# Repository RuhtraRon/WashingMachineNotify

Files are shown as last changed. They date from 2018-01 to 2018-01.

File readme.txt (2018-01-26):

Install the toolchain following:

https://github.com/espressif/arduino-esp32

(which really is just download the repo to specific folder and run get.py)

If the drivers don't autmatically load when connecting with USB, follow:

https://wiki.wemos.cc/downloads

BILL OF MATERIALS:

Descriptoin	Part Number	Cost	Shipping	Quantity	Total
Microprocessor	Lolin32 lite	$4.90	$1.81		1		$4.90
Accelerometer	LIS3DH		$4.95	$10		1		$4.95
Battery		2000mAh		$12.50	^		1		$12.50
Motherboard			$4.95	free		1		$4.95
Case				$19.76	free		1		$19.76
Magnets				$0.26	free		2		$0.52
Headers	Female			$0.04	^		36		$1.59
Headers	Male			$0.01	^		36		$0.50

Needed Libraries Included

Gerber files for motherboard in zip file included

STL for enclosure included (needes updated)

To Use End Product:
Power device on (connect battery)
Use smartphone or computer to connect to SSID 'WashingMachine'
If captive portal doesn't launch, point browser to 192.168.4.1
Follow prompts, select your SSID, enter Wifi password, Ifttt Event Name, and Ifttt Maker Key
    Ifttt maker key can be found at https://ifttt.com/maker_webhooks, click Documentation
    Make sure to add the webhooks service first, and create the applet you want fired
To restore to factory settings, press Reset button or power off device

Values to change in WashingMachineNotify.ino:
#define TIME_TO_SLEEP  300      /* Snooze time between re-notifies */
#define AWAKE_TIME 10000 //milliseconds to wait for another vibration before sleep
#define NOTIFY_THRESHOLD 270000 //milliseconds of vibration before sending notification
#define TIMEOUT 120 //seconds for capture portal to be active
#define NOTIFY_DELAY 120 //seconds to wait before sending first notify

Todo: 
Update to Wemos Lolin32 (not lite)

Sources:
Accelerometer - https://github.com/alexspurling/washingmachine
WifiManger - https://github.com/zhouhan0126/WIFIMANAGER-ESP32

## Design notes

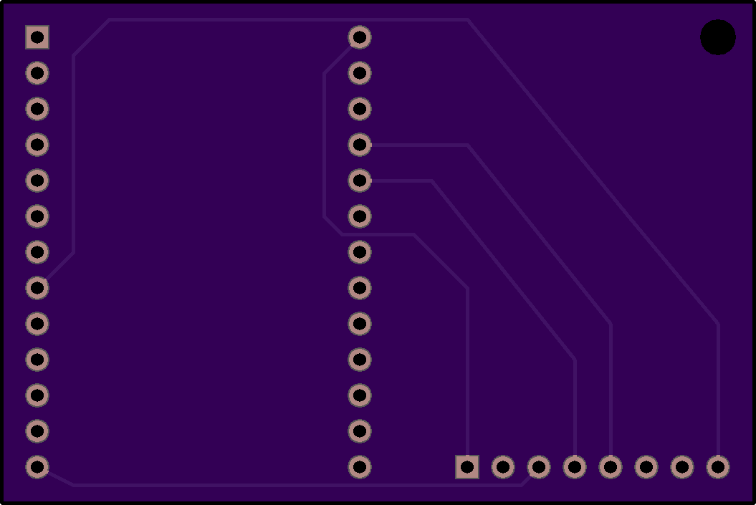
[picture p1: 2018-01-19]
wmnotify.png

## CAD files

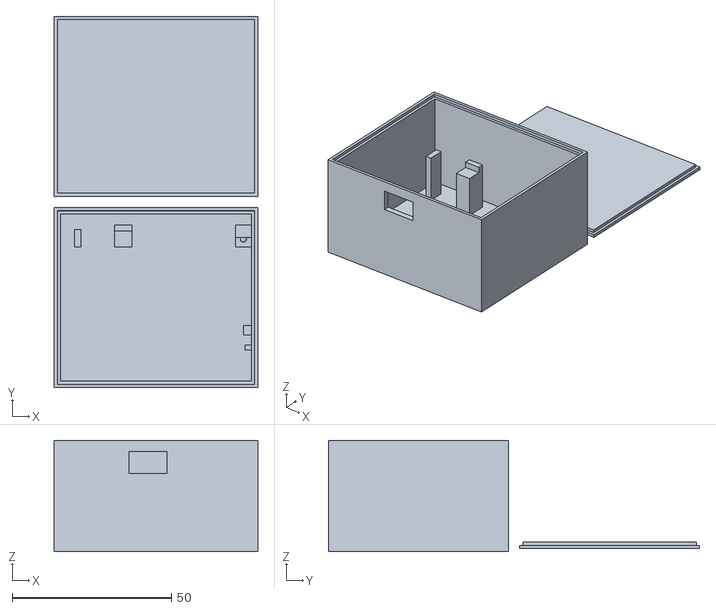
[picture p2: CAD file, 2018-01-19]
WashingMachineBox.stl
64.0 x 116.5 x 35.0

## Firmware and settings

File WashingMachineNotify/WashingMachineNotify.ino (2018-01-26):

#include <WiFi.h>
#include <rom/rtc.h>
#include <DNSServer.h>
#include <WebServer.h>
#include <WiFiManager.h>
#include <WiFiClientSecure.h>
#include <IFTTTMaker.h>
#include "time.h"

#define SDA_PIN 23
#define SCL_PIN 18

RTC_DATA_ATTR char event_name[64] = "IFTTT_EVENT_NAME";
RTC_DATA_ATTR char ifttt_key[32] = "IFTTT_MAKER_KEY";

#define ACCEL 0x18 //I2C device address
#define CTRL_REG1 0x20 //Data rate selection and X, Y, Z axis enable register
#define CTRL_REG2 0x21 //High pass filter selection
#define CTRL_REG3 0x22 //Control interrupts
#define CTRL_REG4 0x23 //BDU
#define CTRL_REG5 0x24 //FIFO enable / latch interrupts

#define INT1_CFG 0x30 //Interrupt 1 config
#define INT1_SRC 0x31 //Interrupt status - read in order to reset the latch
#define INT1_THS 0x32 //Define threshold in mg to trigger interrupt
#define INT1_DURATION 0x33 //Define duration for the interrupt to be recognised (not sure about this one)

//Read this value to set the reference values against which accel values are compared when calculating a threshold interrupt
//Also called the REFERENCE register in the datasheet
#define HP_FILTER_RESET 0x26 

#define REG_X 0x28
#define REG_Y 0x2A
#define REG_Z 0x2C

#define uS_TO_S_FACTOR 1000000  /* Conversion factor for micro seconds to seconds */
#define TIME_TO_SLEEP  300      /* Snooze time between re-notifies */
#define AWAKE_TIME 10000 //milliseconds to wait for another vibration before sleep
#define NOTIFY_THRESHOLD 270000 //milliseconds of vibration before sending notification
#define TIMEOUT 120 //seconds for capture portal to be active
#define NOTIFY_DELAY 120 //seconds to wait before sending first notify

const char* ntpServer = "pool.ntp.org";
const long  gmtOffset_sec = -18000;
const int   daylightOffset_sec = 3600;

bool button_press = false;

const int ledPin = 22;
int ledState = HIGH;
const int intPin = 25;

WiFiClientSecure secureclient;
IFTTTMaker ifttt(ifttt_key, secureclient);

WiFiManager wifiManager;

RTC_DATA_ATTR int bootCount = 0;
RTC_DATA_ATTR int prevState = 0;
RTC_DATA_ATTR bool renotify = false;
RTC_DATA_ATTR bool first_notify = false;
unsigned long bootTime = 0;
unsigned long machineOffTime = 0;
unsigned long blinkTime = 0;
unsigned long startWM = 0;

RTC_DATA_ATTR struct tm first_notify_time;

void blinkLed(){
  ledState = !ledState;
  digitalWrite(ledPin, ledState);
}

void print_wakeup_reason(){
  esp_sleep_wakeup_cause_t wakeup_reason;

  wakeup_reason = esp_sleep_get_wakeup_cause();
  Serial.print("wakeup_reason: ");
  Serial.println(wakeup_reason);
  switch(wakeup_reason)
  {
    case 1  : Serial.println("Wakeup caused by external signal using RTC_IO"); break; //if(!first_notify){renotify=false;}
    case 2  : Serial.println("Wakeup caused by external signal using RTC_CNTL"); break;
    case 3  : Serial.println("Wakeup caused by timer"); break;
    case 4  : Serial.println("Wakeup caused by touchpad"); break;
    case 5  : Serial.println("Wakeup caused by ULP program"); break;
    default : Serial.println("Wakeup was not caused by deep sleep"); renotify=false; first_notify = false; break;
  }
}

void verbose_print_reset_reason(RESET_REASON reason)
{
  switch ( reason)
  {
    case 1  : Serial.println ("Vbat power on reset"); button_press=true; break;
    case 3  : Serial.println ("Software reset digital core");break;
    case 4  : Serial.println ("Legacy watch dog reset digital core");break;
    case 5  : Serial.println ("Deep Sleep reset digital core");break;
    case 6  : Serial.println ("Reset by SLC module, reset digital core");break;
    case 7  : Serial.println ("Timer Group0 Watch dog reset digital core");break;
    case 8  : Serial.println ("Timer Group1 Watch dog reset digital core");break;
    case 9  : Serial.println ("RTC Watch dog Reset digital core");break;
    case 10 : Serial.println ("Instrusion tested to reset CPU");break;
    case 11 : Serial.println ("Time Group reset CPU");break;
    case 12 : Serial.println ("Software reset CPU");break;
    case 13 : Serial.println ("RTC Watch dog Reset CPU");break;
    case 14 : Serial.println ("for APP CPU, reseted by PRO CPU");break;
    case 15 : Serial.println ("Reset when the vdd voltage is not stable");break;
    case 16 : Serial.println ("RTC Watch dog reset digital core and rtc module");button_press=true;break;
    default : Serial.println ("NO_MEAN");
  }
}

void wifiConfig(){
  #define STA_SSID "YOUR_SSID"
  #define STA_PASS "YOUR_PASSWORD"
  WiFi.begin(STA_SSID, STA_PASS);
  wifiWait();
}

void wifiWait(){
    Serial.println("Waiting for WiFi");
    int wifi_wait_count = 30;
    int count = 0;
    while ((WiFi.status() != WL_CONNECTED)&&(count < wifi_wait_count)) {
        delay(500);
        Serial.print(".");
        count++;
    }
    if (count >= wifi_wait_count){
      esp_sleep_enable_timer_wakeup(1 * uS_TO_S_FACTOR);
      esp_deep_sleep_start();
    }
    Serial.println("");
    Serial.println("WiFi connected");
    Serial.println("IP address: ");
    Serial.println(WiFi.localIP());
}

void printAccel(int vibrations) {
  float x = getAccel(readReg(REG_X));
  float y = getAccel(readReg(REG_Y));
  float z = getAccel(readReg(REG_Z));

  Serial.print("Read: ");
  printFloat(x, 3);
  Serial.print(", ");
  printFloat(y, 3);
  Serial.print(", ");
  printFloat(z, 3);
  Serial.print(", ");
  Serial.println(vibrations);
  
  writeReg(INT1_CFG, 0x2a);
}

void iftttsend(){
  //triggerEvent takes an Event Name and then you can optional pass in up to 3 extra Strings
  if(ifttt.triggerEvent(event_name)){
    Serial.println("IFTTT Successfully sent");
  } else
  {
    Serial.println("IFTTT Failed!");
  }
}

struct tm timeinfo;
void printLocalTime()
{
  if(!getLocalTime(&timeinfo)){
    Serial.println("Failed to obtain time");
    return;
  }
  Serial.println(&timeinfo, "%A, %B %d %Y %H:%M:%S");
}

void setupAccel(){
  writeReg(CTRL_REG1, 0x47); //Set data rate to 50hz. Enable X, Y and Z axes
  //1 - BDU: Block data update. This ensures that both the high and the low bytes for each 16bit represent the same sample
  //0 - BLE: Big/little endian. Set to little endian
  //00 - FS1-FS0: Full scale selection. 00 represents +-2g
  //1 - HR: High resolution mode enabled.
  //00 - ST1-ST0: Self test. Disabled
  //0 - SIM: SPI serial interface mode. Default is 0.
  writeReg(CTRL_REG4, 0x88);
  writeReg(CTRL_REG2, 0x09);//2 Write 09h into CTRL_REG2 // High-pass filter enabled on data and interrupt1
  writeReg(CTRL_REG3, 0x40);//3 Write 40h into CTRL_REG3 // Interrupt driven to INT1 pad
  //4 Write 00h into CTRL_REG4 // FS = 2 g
  writeReg(CTRL_REG5, 0x08);//5 Write 08h into CTRL_REG5 // Interrupt latched
  writeReg(INT1_THS, 0x04);// Threshold as a multiple of 16mg. 4 * 16 = 64mg
  writeReg(INT1_DURATION, 0x00);// Duration = 0 not quite sure what this does yet
  // Read the reference register to set the reference acceleration values against which
  // we compare current values for interrupt generation
  readReg(HP_FILTER_RESET);//8 Read HP_FILTER_RESET
  writeReg(INT1_CFG, 0x2a);//9 Write 2Ah into INT1_CFG // Configure interrupt when any of the X, Y or Z axes exceeds (rather than stay below) the threshold
  readReg(INT1_SRC);
}

void wifiManagerConfig(){
  // The extra parameters to be configured (can be either global or just in the setup)
  // After connecting, parameter.getValue() will get you the configured value
  // id/name placeholder/prompt default length

  WiFiManagerParameter custom_event_name("name", "event name", event_name, 64);
  WiFiManagerParameter custom_ifttt_key("key", "ifttt key", ifttt_key, 32);

  wifiManager.addParameter(&custom_event_name);
  wifiManager.addParameter(&custom_ifttt_key);

  wifiManager.setBreakAfterConfig(true);
  wifiManager.setConfigPortalTimeout(TIMEOUT);

  startWM = millis();
  
  if (!button_press){
    wifiManager.autoConnect("WashingMachine");
  } else {
    wifiManager.startConfigPortal("WashingMachine");
  }
  
  if ((WiFi.status() != WL_CONNECTED)&&(millis() > startWM + (TIMEOUT*1000))){ //setConfigPortalTimeout must have triggered
    Serial.println("Going to sleep, portal timeout");
    esp_deep_sleep_start();
  }
  strcpy(event_name, custom_event_name.getValue());
  strcpy(ifttt_key, custom_ifttt_key.getValue());

  Serial.print("event_name: ");
  Serial.println(event_name);
  Serial.print("ifttt_key: ");
  Serial.println(ifttt_key);

  wifiWait();
}

void setup() {
  Serial.begin(115200);
  ++bootCount;
  Serial.println("Boot number: " + String(bootCount));
  pinMode(ledPin, OUTPUT);
  digitalWrite(ledPin, ledState); //off
  print_wakeup_reason();
  verbose_print_reset_reason(rtc_get_reset_reason(0));
  initI2C();
  setupAccel();
  pinMode(intPin, INPUT);
  attachInterrupt(intPin, wakeUp, RISING);
  Serial.println("Accelerometer enabled");
  
  esp_sleep_enable_ext0_wakeup(GPIO_NUM_25, HIGH);

  blinkLed(); //on

  wifiManagerConfig();
//  wifiConfig();

  blinkLed(); //off
  bootTime = millis();
  Serial.print("Re-notify: ");
  Serial.println(renotify);
  configTime(gmtOffset_sec, daylightOffset_sec, ntpServer);
  printLocalTime();
  Serial.println(&first_notify_time, "%A, %B %d %Y %H:%M:%S");
}

float getAccel(int16_t accel) {
  return float(accel) / 16000;
}

volatile bool machineOn = false;
volatile unsigned int vibrations = 0;
unsigned int prev_vibrations = 0;

int activeLoopInterval = 200; //Loop 5 times a second

bool started = false;
float readdata = 0.0;

void loop() {  
  if (!started) { //first power on
      started = true;
      //Reset the interrupt when we are actually ready to receive it
      readReg(INT1_SRC);
    }
  if (machineOn) {
    readReg(INT1_SRC);
    delay(activeLoopInterval);
    blinkLed();
    printAccel(vibrations);

    if (vibrations > prev_vibrations){
      prev_vibrations = vibrations;
    } else{
      machineOn = false;
      machineOffTime = millis();
    }
    if (renotify && vibrations > 10){
      renotify = false;
      int i = 100;
      while (i >0){
        blinkLed();
        delay(50);
        i--;
      }
    }
  } else if (millis() - machineOffTime > AWAKE_TIME) {
    if ((millis() - bootTime > (NOTIFY_THRESHOLD)) || renotify) {
      if (!renotify){
        first_notify = true;
        Serial.println("Turning first_notify on");
        getLocalTime(&first_notify_time);
        Serial.print("Setting first_notify_time: ");
        Serial.println(&first_notify_time, "%A, %B %d %Y %H:%M:%S");
        renotify = true;
        Serial.println("Re-notify On");
      }
      printLocalTime();
      double notifydifftime = difftime(mktime(&timeinfo),mktime(&first_notify_time));
      Serial.print("Time Diff: ");
      Serial.println(notifydifftime);
      int sleep_time = 0;
      if (first_notify){
        sleep_time = (NOTIFY_DELAY-notifydifftime);
      } else {
        sleep_time = (TIME_TO_SLEEP-notifydifftime);
      }
      if (sleep_time < 0) {
        iftttsend();
        first_notify = false;
        Serial.println("Turning first_notify off");
        getLocalTime(&first_notify_time);
        Serial.print("Setting first_notify_time: ");
        Serial.println(&first_notify_time, "%A, %B %d %Y %H:%M:%S");
        sleep_time = TIME_TO_SLEEP;
      }
      esp_sleep_enable_timer_wakeup(sleep_time * uS_TO_S_FACTOR);
      Serial.print("Sleeping for: ");
      Serial.println(sleep_time);
    }
    writeReg(CTRL_REG1, 0x2f); //Set data rate to 1z. Enable X, Y and Z axes in low power mode
    writeReg(CTRL_REG4, 0x0); //Turn off BDU, turn off high precision mode
    readReg(HP_FILTER_RESET); //Reset the reference state (seems to be necessary when changing the ODR)
    readReg(INT1_SRC); //Reset the interrupt so it will trigger when we are asleep
    Serial.println("Going to sleep now");
    esp_deep_sleep_start();

  } else {
    //Slow flash when idling
    if (millis() - blinkTime > 1000){
      blinkTime = millis();
      blinkLed();
      printAccel(vibrations);
    }
  }
}

void wakeUp() {
  machineOn = true;
  vibrations++;
}

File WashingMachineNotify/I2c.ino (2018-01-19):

#include <Wire.h>

void initI2C() {
  Wire.begin(SDA_PIN, SCL_PIN);
  delay(100);
  Serial.println("Getting ACCEL ID:");
  Serial.println(readByte(0x0F));
}

byte readByte(byte reg) {
  Wire.beginTransmission(ACCEL);
  Wire.write(reg);
  Wire.endTransmission();
  Wire.requestFrom(byte(ACCEL), byte(1));
  
  if (Wire.available() == 1) {
    return Wire.read();
  }
  return 0;
}

int16_t readReg(byte reg) {
  byte low = readByte(reg);
  byte high = readByte(reg + 1);
  return int16_t(high << 8) | (int16_t)low;
}

void writeReg(byte reg, byte val) {
  Wire.beginTransmission(ACCEL);
  Wire.write(reg);
  Wire.write(val);
  Wire.endTransmission();
}
